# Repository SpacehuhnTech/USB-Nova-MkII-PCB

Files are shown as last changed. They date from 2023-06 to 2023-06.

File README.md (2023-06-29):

# USB-Nova-MkII-PCB

USB Nova MkII Hardware Design Files

USB Nova is a cute little USB “drive” that acts as a keyboard, much like the USB Rubber Ducky, WiFi Duck, and other BadUSBs. 

This is the USB-C version.

Learn about the Project at [usbnova.com](https://usbnova.com).  
Buy one at [spacehuhn.store](https://spacehuhn.store/products/usb-nova).  

USB Nova Picture

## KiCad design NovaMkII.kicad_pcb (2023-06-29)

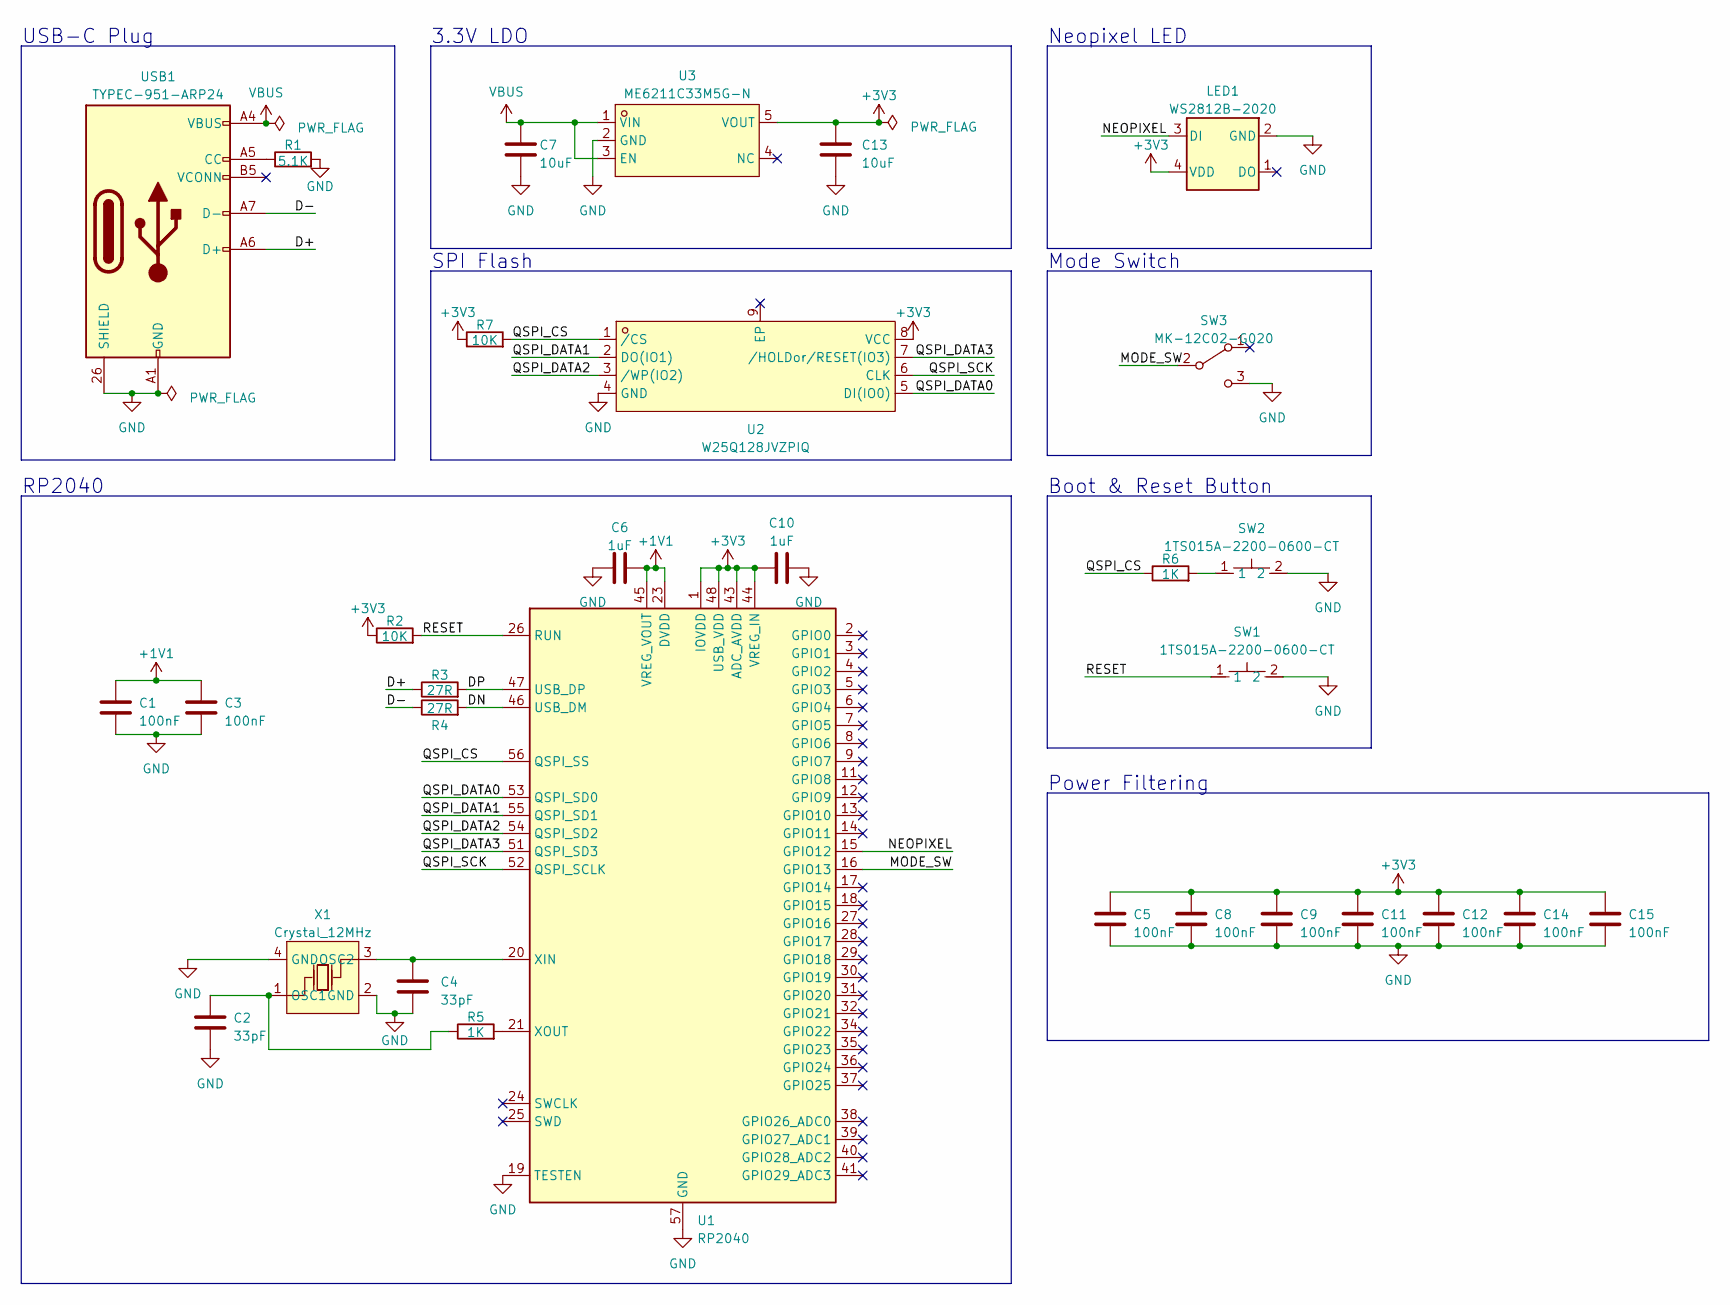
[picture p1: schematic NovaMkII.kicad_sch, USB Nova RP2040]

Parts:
C1, C3, C5, C8, C9, C11, C12, C14, C15: 100nF; C_0402_1005Metric
C2, C4: 33pF; C_0402_1005Metric
C6, C10: 1uF; C_0603_1608Metric
C7, C13: 10uF; C_0603_1608Metric
LED1: WS2812B-2020; LED-SMD_4P-L2.0-W2.0-TL_WS2812B-2020; MPN C965555
R1: 5.1K; R_0402_1005Metric
R2, R7: 10K; R_0402_1005Metric
R3, R4: 27R; R_0402_1005Metric; MPN C2909343
R5, R6: 1K; R_0402_1005Metric
SW1, SW2: 1TS015A-2200-0600-CT; SW-SMD_L3.0-W2.0-LS3.5; MPN C398748
SW3: MK-12C02-G020; SW_MK-12C02-G020; MPN C963206
U1: RP2040; QFN-56-1EP_7x7mm_P0.4mm_EP3.2x3.2mm; MPN C2040
U2: W25Q128JVZPIQ; WSON-8_L6.0-W5.0-P1.27-BL-EP; MPN C190862
U3: ME6211C33M5G-N; SOT-25-5_ME6211C33M5G; MPN C82942
USB1: TYPEC-951-ARP24; USB-C-SMD_TYPEC-951-ARP24; MPN C2856663
X1: Crystal_12MHz; OSC-SMD_4P-L3.2-W2.5-BL; MPN C9002

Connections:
+1V1: C1.1, C3.1, C6.2, U1.23 (DVDD), U1.45 (VREG_VOUT), U1.50 (DVDD)
+3V3: C5.1, C8.1, C9.1, C10.1, C11.1, C12.1, C13.1, C14.1, C15.1, LED1.4 (VDD), R2.1, R7.1, U1.1 (IOVDD), U1.10 (IOVDD), U1.22 (IOVDD), U1.33 (IOVDD), U1.42 (IOVDD), U1.43 (ADC_AVDD), U1.44 (VREG_IN), U1.48 (USB_VDD), U1.49 (IOVDD), U2.8 (VCC), U3.5 (VOUT)
/D+: R3.1, USB1.A6 (D+)
/D-: R4.1, USB1.A7 (D-)
/DN: R4.2, U1.46 (USB_DM)
/DP: R3.2, U1.47 (USB_DP)
/MODE_SW: SW3.2 (B), U1.16 (GPIO13)
/NEOPIXEL: LED1.3 (DI), U1.15 (GPIO12)
/QSPI_CS: R6.1, R7.2, U1.56 (QSPI_SS), U2.1 (/CS)
/QSPI_DATA0: U1.53 (QSPI_SD0), U2.5 (DI(IO0))
/QSPI_DATA1: U1.55 (QSPI_SD1), U2.2 (DO(IO1))
/QSPI_DATA2: U1.54 (QSPI_SD2), U2.3 (/WP(IO2))
/QSPI_DATA3: U1.51 (QSPI_SD3), U2.7 (/HOLDor/RESET(IO3))
/QSPI_SCK: U1.52 (QSPI_SCLK), U2.6 (CLK)
/RESET: R2.2, SW1.1, U1.26 (RUN)
GND: C1.2, C2.2, C3.2, C4.2, C5.2, C6.1, C7.1, C8.2, C9.2, C10.2, C11.2, C12.2, C13.2, C14.2, C15.2, LED1.2 (GND), R1.2, SW1.2, SW2.2, SW3.3 (C), U1.19 (TESTEN), U1.57 (GND), U2.4 (GND), U3.2 (GND), USB1.25 (SHIELD), USB1.26 (SHIELD), USB1.A1 (GND), USB1.A12 (GND), USB1.B1 (GND), USB1.B12 (GND), X1.2 (GND), X1.4 (GND)
unnamed: R6.2, SW2.1
unnamed: C4.1, U1.20 (XIN), X1.3 (OSC2)
unnamed: R5.2, U1.21 (XOUT)
unnamed: R1.1, USB1.A5 (CC)
unnamed: C2.1, R5.1, X1.1 (OSC1)
VBUS: C7.2, U3.1 (VIN), U3.3 (EN), USB1.A4 (VBUS), USB1.A9 (VBUS), USB1.B4 (VBUS), USB1.B9 (VBUS)

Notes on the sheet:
USB-C Plug
SPI Flash
Neopixel LED
Power Filtering
Mode Switch
RP2040
3.3V LDO
Boot & Reset Button

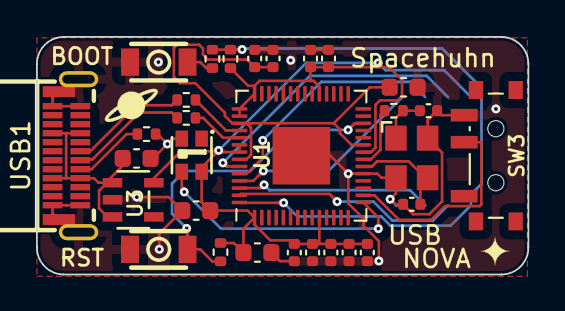
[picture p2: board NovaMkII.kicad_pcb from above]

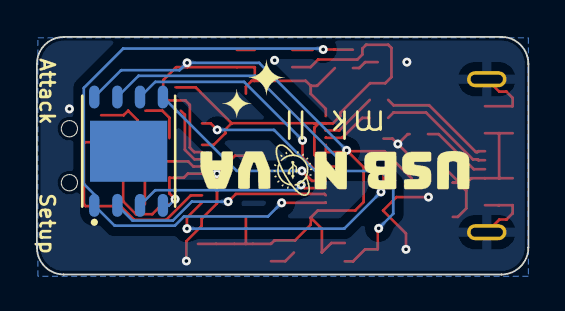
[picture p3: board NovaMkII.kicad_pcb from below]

Board: 2 copper layers, 27.3 x 13.2 mm, 36 parts (4 on the bottom side), 22 nets.

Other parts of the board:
G1: LOGO; nova
G4: LOGO; star_small
G5, G8: LOGO; star_tiny
G6: LOGO; planet_small
